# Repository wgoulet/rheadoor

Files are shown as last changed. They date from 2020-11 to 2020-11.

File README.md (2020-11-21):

Rheadoor
========

This project was inspired by a buddy who recently started raising chickens here in Chicago.

The Rheadoor is a combination of a webservice (and eventually a front end website) that is going
to control various functions of a chicken coop, starting with an electronic door opening/closing
system. The hardware is using a Raspberry Pi 4 with various controllers to interface with motors
that will control the door functions.

Current hardware manifest:
Sparkfun EasyDriver - header pins soldered
Stepper motor 17HS16-2004S

Requires Python 3.7 or greater and a Raspberry Pi 4 running latest Raspian OS.

Wiring Diagram
--------------
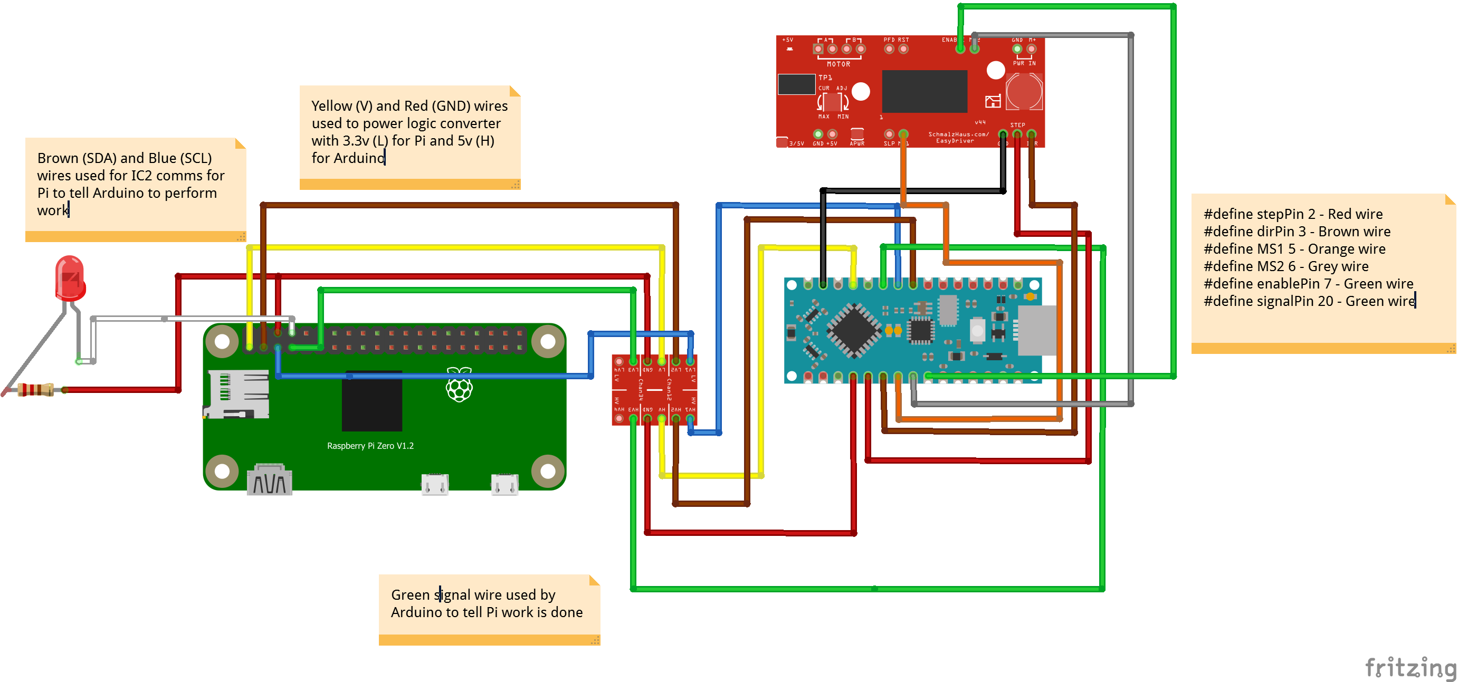
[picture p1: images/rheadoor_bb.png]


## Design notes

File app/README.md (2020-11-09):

# Backend API Application for driving the RheaDoor

The backend application is built using Python with the FastAPI framework. The application exposes REST endpoints that are called by the Raspberry PI clients when they need to check in and complete work, as well as the frontend React application used by users.

## Security

Since I've had to dig deep into the guts of OAuth2.0/OIDC for #dayjob, I decided to implement the authentication and authorization framework for this application using KeyCloak.

The app's REST API uses the Starlette OAuth2 API middleware to protect the secured endpoints. The API expects that all API requests include an access token in the Authorization header. Decisions on whether or not the API will act on the requests is based on whether or not the tokens issued to API callers contain the correct audience (e.g. authorization is based on if the token contains the correct audience.)

For non-interactive API clients running on the Raspberry PI, having a valid token with the correct audience is sufficient to perform the action. For interactive users using the React front-end, an additional check is made based on the user's role (as returned by Keycloak in the user's ID token) to determine if the user is permitted to perform an action.

## Design of the backend application

The FastAPI application is hosted by the uvicorn ASGI webserver. The OAuth2 API middleware is configured with the URL, issuer and JWKS URL for the KeyCloak server.

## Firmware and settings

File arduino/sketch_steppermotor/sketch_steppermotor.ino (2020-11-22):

#define stepPin 2
#define dirPin 3
#define MS1 5
#define MS2 6
#define enablePin 7
#define signalPin 20
#define CMDMAX 25
#include <Wire.h>

bool hasRan = false;
float numRotations = 5;
int cmdComplete = false;
char cmd[CMDMAX];
int cmdcount = 0;
int cmds[4];

void setup() {
  // put your setup code here, to run once:
  Wire.begin(0x8);
  Wire.onReceive(receiveEvent);  
  pinMode(stepPin, OUTPUT);
  pinMode(dirPin, OUTPUT);
  pinMode(MS1, OUTPUT);
  pinMode(MS2, OUTPUT);
  pinMode(enablePin, OUTPUT);
  pinMode(signalPin, OUTPUT);
  resetEDPins(); //Set step, direction, microstep and enable pins to default states
  Serial.begin(9600); //Open Serial connection for debugging
  Serial.println("Begin motor control");
}

void receiveEvent(int numBytesReceived)
{
  Serial.println("Got an event");
  // Fill the command array with data that is received; the command
  // will actually be executed in the main loop. Found that executing
  // the call here caused timing issues, so better to get and store
  // the data and let other functions act on the received data.
  while(Wire.available())
  {
    Serial.print("Storing event; cmdcount is");
    Serial.println(cmdcount);
    int c = Wire.read();
    cmds[cmdcount] = c;
    cmdcount++;
   }
}

void resetEDPins()
{
  digitalWrite(stepPin, LOW);
  digitalWrite(dirPin, LOW);
  digitalWrite(MS1, LOW);
  digitalWrite(MS2, LOW);
  digitalWrite(enablePin, HIGH);
  digitalWrite(signalPin, LOW);
}

void moveForward(int numRotations,int fractionalRotations)
{
  Serial.println("About to move forward");
  
  // 200 steps rotates motor fully so multiply by numRotations
  Serial.println("rotations");
  Serial.println(numRotations);
  // To support partial rotations and allow callers to send
  // us fractional turns, fractionalRotations is expressed as
  // the fractional part of a turn (0-100). To convert it to
  // an actual rotation of the motor, need to multiply this by
  // 2.
  int steps = (200.0 * numRotations) + (fractionalRotations * 2);
  digitalWrite(dirPin,LOW );
  Serial.println(steps);
  for(int x=0; x < int(steps); x++)
  {
    digitalWrite(stepPin,HIGH);
    delay(1);
    digitalWrite(stepPin,LOW);
    delay(1);
  }
  digitalWrite(signalPin,HIGH);
  delay(50);
  digitalWrite(signalPin,LOW);
}

void moveBackward(int numRotations,int fractionalRotations)
{
  Serial.println("About to move backwards");
  
  // 200 steps rotates motor fully so multiply by numRotations
  Serial.println("rotations");
  Serial.println(numRotations);
  // To support partial rotations and allow callers to send
  // us fractional turns, fractionalRotations is expressed as
  // the fractional part of a turn (0-100). To convert it to
  // an actual rotation of the motor, need to multiply this by
  // 2.
  int steps = (200.0 * numRotations) + (fractionalRotations * 2);
  digitalWrite(dirPin,HIGH);
  Serial.println(steps);
  for(int x=0; x < int(steps); x++)
  {
    digitalWrite(stepPin,HIGH);
    delay(1);
    digitalWrite(stepPin,LOW);
    delay(1);
  }
  digitalWrite(signalPin,HIGH);
  delay(50);
  digitalWrite(signalPin,LOW);
}

void loop() {
  // put your main code here, to run repeatedly:
  while(cmds[1] != 0)
  {
    if(cmds[1] == 1) // 1 is forward
    {
      digitalWrite(enablePin,LOW);
      moveForward(cmds[2],cmds[3]);
      cmds[0] = 0;
      cmds[1] = 0;
      cmds[2] = 0;
      cmds[3] = 0;
      cmdcount = 0;
    }
    else if(cmds[1] == 2) // 2 is backward
    {
      digitalWrite(enablePin,LOW);
      moveBackward(cmds[2],cmds[3]);
      cmds[0] = 0;
      cmds[1] = 0;
      cmds[2] = 0;
      cmds[3] = 0;
      cmdcount = 0;
    }
    delay(1);
  }
  while(Serial.available())
  {
    char userinput = Serial.read();
    if(userinput != ' ')
    {
      digitalWrite(enablePin,LOW);
      moveForward(numRotations,0);
      resetEDPins();
    }
  }
  
  
}

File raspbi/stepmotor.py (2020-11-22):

# Stepper motor controller script
# Equipment: 
# Sparkfun Easydriver ROB-12779
# Bipolar stepper motor 17HS16-2004S
# Power supply: 12v 1.0A <-- wrong power supply not 
# providing sufficient amps can make it difficult to figure
# out if your wiring or code is bad. Make sure you are providing
# enough power. With the easydriver, also note the the potentiometer
# is defaulted to halfway setting, meaning it is only delivering
# about half of the potential amps it can deliver. So be sure
# to adjust the poteniometer accordingly (I cranked it up to
# 750ma for best operation. Also note the pot on the easydriver
# isn't marked with reliable min/max settings, so measure the
# voltage at TP1 and ground and when the volts are max ~5v, you 
# know you have the pot maxed out). Finally, learned the hard way
# that since the Easydriver doesn't ship with the header pins soldered
# on, while it is tempting to just run jumpers through the board from
# the motors/raspberry pi into a breadboard, this type of connectivity
# caused me fits when trying to drive the motor. When I soldered header
# pins to the Easydriver and plugged it into my breadboard, the motor
# motion became incredibly smooth.

import RPi.GPIO as GPIO
from smbus import SMBus
import time
import math
import asyncio
import sys
import re

# Maps the GPIO pins to the step motor controller
# functions
ENABLE = 21
MS2 = 20
DIR = 16
STEP = 12
MS1 = 1
RESET = 7
SIGNAL = 4
LEDSTATUS = 14

class StepMotor:

    async def initController(self):
        GPIO.setmode(GPIO.BCM)
        GPIO.setup(ENABLE,GPIO.OUT)
        GPIO.setup(MS1,GPIO.OUT)
        GPIO.setup(MS2,GPIO.OUT)
        GPIO.setup(STEP,GPIO.OUT)
        GPIO.setup(DIR,GPIO.OUT)
        GPIO.setup(RESET,GPIO.OUT)
        GPIO.setup(SIGNAL,GPIO.IN)

        GPIO.output(ENABLE,GPIO.LOW)
        GPIO.output(MS1,GPIO.HIGH)
        GPIO.output(MS2,GPIO.LOW)
        GPIO.output(STEP,GPIO.LOW)
        GPIO.output(DIR,GPIO.LOW)
        GPIO.output(RESET,GPIO.LOW)
        GPIO.output(RESET,GPIO.HIGH)
    
    def flashOKStatus(self):
        GPIO.setmode(GPIO.BCM)
        GPIO.setup(LEDSTATUS,GPIO.OUT)
        for i in range(0,5):
            GPIO.output(LEDSTATUS,GPIO.HIGH);
            time.sleep(1)
            GPIO.output(LEDSTATUS,GPIO.LOW);

    async def getArduinoStatus(self):
        print("checking status @ {0}".format(time.asctime(time.localtime())))
        GPIO.setmode(GPIO.BCM)
        GPIO.setup(SIGNAL,GPIO.IN)
        while(True):
            try:
                signal = GPIO.input(SIGNAL)
                if(signal == GPIO.HIGH):
                    print("Got result ok")
                    result = 0x1
                    break
            except IOError: 
                print("error getting status")
                pass
        return result

    async def ardMotorForward(self,numRotations):
        addr = 0x8
        bus = SMBus(1) # indicates /dev/ic2-1
        # If we are passed a float, we need to convert
        # it into the full turns value and the fractional
        # turns.
        fullturn = math.floor(numRotations)
        if(fullturn == 0):
            fraction = int(numRotations * 100)
        else:
            fraction = int((numRotations % fullturn) * 100)
        # Protocol we send is 4 ints: first is register addr of 0x0,
        # second is move direction (1 - forward, 2 - backward)
        # 3rd and fourth are full and fractional turns
        bus.write_i2c_block_data(addr,0x0,[1,fullturn,fraction])
        bus.close()
        result = await self.getArduinoStatus()
        print(result)
        if(result == 0x1):
            print("Finished work @ {0}".format(time.asctime(time.localtime())))
            self.flashOKStatus()
            
    async def ardMotorBackward(self,numRotations):
        addr = 0x8
        bus = SMBus(1) # indicates /dev/ic2-1
        # If we are passed a float, we need to convert
        # it into the full turns value and the fractional
        # turns
        fullturn = math.floor(numRotations)
        if(fullturn == 0):
            fraction = int(numRotations * 100)
        else:
            fraction = int((numRotations % fullturn) * 100)
        bus.write_i2c_block_data(addr,0x0,[2,fullturn,fraction])
        bus.close()
        result = await self.getArduinoStatus()
        print(result)
        if(result == 0x1):
            print("Finished work @ {0}".format(time.asctime(time.localtime())))
            self.flashOKStatus()

    async def motorForward(self,numRotations):
        self.initController()
        # Drive the motor forward
        GPIO.output(DIR,GPIO.LOW)
        # 400 is full rotation for motor so multiple this
        # by number of desired rotations
        if (numRotations < 1):
            turns = float(400) * numRotations
        else:
            turns = 400 * numRotations
        if (turns < 0):
            turns = turns * -1

        for i in range(0,int(turns)):
            GPIO.output(STEP,GPIO.HIGH)
            time.sleep(.001)
            GPIO.output(STEP,GPIO.LOW)

        GPIO.output(ENABLE,GPIO.HIGH)
        GPIO.cleanup()

    async def logicCheck(self):
        self.initController()
        GPIO.output(DIR,GPIO.HIGH)
        time.sleep(2)
        GPIO.output(DIR,GPIO.LOW)
        time.sleep(2)
        GPIO.output(DIR,GPIO.HIGH)

    async def motorBackward(self,numRotations):
        self.initController()
        # Drive the motor backward
        GPIO.output(DIR,GPIO.HIGH)
        # 400 is full rotation for motor so multiple this
        # by number of desired rotations
        if (numRotations < 1):
            turns = float(400) * numRotations
        else:
            turns = 400 * numRotations
        if (turns < 0):
            turns = turns * -1

        for i in range(0,int(turns)):
            GPIO.output(STEP,GPIO.HIGH)
            time.sleep(.001)
            GPIO.output(STEP,GPIO.LOW)

        GPIO.output(ENABLE,GPIO.HIGH)
        GPIO.cleanup()

    async def motorDiffSteps(self):
        self.initController()
        # Drive the motor backward
        GPIO.output(DIR,GPIO.LOW)
        for i in range(0,1000):
            GPIO.output(MS1,GPIO.HIGH)
            GPIO.output(MS2,GPIO.LOW)
            GPIO.output(STEP,GPIO.HIGH)
            time.sleep(.001)
            GPIO.output(STEP,GPIO.LOW)
        time.sleep(1.5)
        for i in range(0,1000):
            GPIO.output(MS1,GPIO.LOW)
            GPIO.output(MS2,GPIO.HIGH)
            GPIO.output(STEP,GPIO.HIGH)
            time.sleep(.001)
            GPIO.output(STEP,GPIO.LOW)
        time.sleep(1.5)
        for i in range(0,1000):
            GPIO.output(MS1,GPIO.HIGH)
            GPIO.output(MS2,GPIO.HIGH)
            GPIO.output(STEP,GPIO.HIGH)
            time.sleep(.001)
            GPIO.output(STEP,GPIO.LOW)
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

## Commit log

2020-10-05 First version of client on Raspberry Pi
2020-10-17 Basic DC motor driver script working
2020-10-17 First version of stepper motor driver
2020-10-19 Got basic motor driver working
2020-10-20 Added notes about adjust pot on the easydriver and added extra function to flip the reset before every motor command
    [runwork.py, stepmotor.py]
2020-10-21 Adjusted step mode to half step to smooth motor action
2020-10-23 Adding baseline stepper script using Adafruit DC MotorHat
2020-10-23 More notes about troubleshooting the easydriver to motor connections
2020-10-24 Added some additional error handling
    [runwork.py]
2020-10-26 First version of arduino driver
2020-10-26 Get basic I2C comms working but motor not moving smoothly
2020-10-26 Updates to send move commands to arduino
2020-10-27 Created new protocol for sending data to the arduino and added support for forward/backward fractional rotations
2020-10-27 Refactored sketch to move motor invocation function into main loop and implemented protocol for comms with Raspberry Pi
2020-10-27 Fixed bug with incorrect handling of fractional turns when less than 1 full turn specified
    [runwork.py, stepmotor.py]
2020-10-27 Added functionality to invoke arduino driver remotely by adding another work type
2020-10-29 Updated pinouts for Arduino Nany Every
2020-10-30 index on main: b18b5de Added functionality to invoke arduino driver remotely by adding another work type
2020-11-01 Basic async flow working
2020-11-01 Switched to GPIO signal to receive status from arduino
2020-11-01 Added support for arduino to signal work completion to raspberry pi via gpio
2020-11-01 Updated main runwork method for async operation of motor
2020-11-01 Added support for an LED indicator when work is completed
2020-11-10 Removed last traces of server side user authentication
2020-11-20 Added some instructions to readme and added error messaging to the stepmotor script
    [stepmotor.py]
2020-11-21 Adding image file of wiring diagram
2020-11-21 Updated readme with wiring diagram
2020-11-21 Convert to png file for image display
    [rheadoor.fzz]
2020-12-06 Fixed table display to not show config changes and updated forward button to use user configured values
2020-12-06 Wired up fine grained control buttons
